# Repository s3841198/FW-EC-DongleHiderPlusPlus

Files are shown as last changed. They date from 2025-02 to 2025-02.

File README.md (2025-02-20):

# DongleHider++ Framework Laptop Expansion Card

This is a fork of LeoDJ's dongle hider plus, it is a slight refinement of the design fitting it into a pcb that is compatible with a stock Framework USB C expansion card.

Simply (permanently) mount the dongle inside the card and still have an USB A port available!  

There even is room and solder pads for an additional dongle. Your imagination (and physics) are the only limits!

See LeoDJ's [thread on Mastodon about the build process etc](https://chaos.social/@LeoDJ/112040053271880119).

<p float="left" style="display: flex; flex-wrap: wrap; align-items: center;">
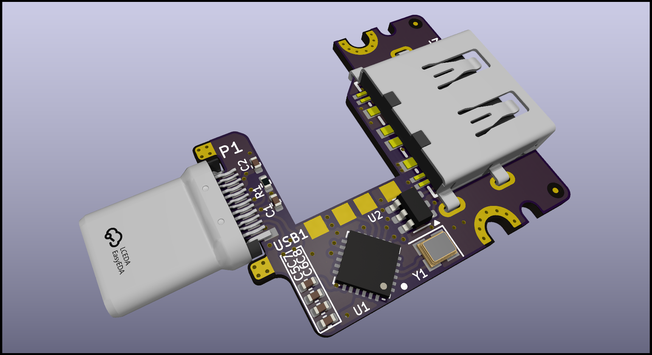
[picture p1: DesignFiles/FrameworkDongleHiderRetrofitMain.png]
  &nbsp;
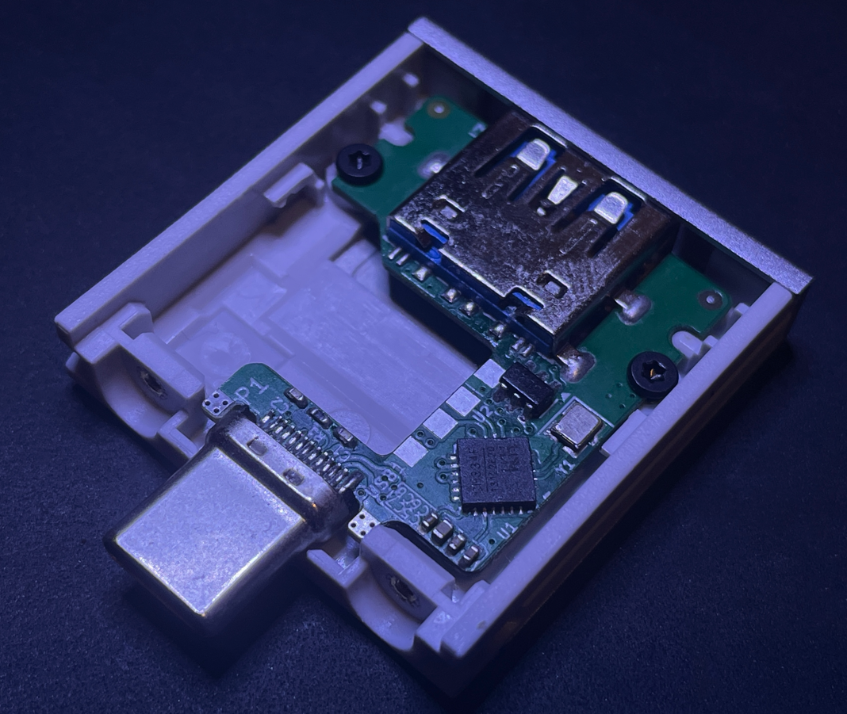
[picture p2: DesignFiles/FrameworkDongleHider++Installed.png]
  
</p>

## Compatibility Notes

The expansion card was only tested on **Windows** and **AMD** Framework **13 and 16** laptops as of right now. There the following behaviour has been observed:
- With only a dongle active, the CH334 hub IC draws around 20mA. (In addition to the ~25mA of the Unifying dongle)
  - When nothing is connected to the hub, it goes to sleep and draws <1mA. (But this is seldomly the case with a dongle permanently attached to it :P )
- Despite earlier fears, the USB 3 "route-around-2.0-hub" topology doesn't seem to cause problems in the wild, except:
- When connected to a **USB4 capable expansion card slot** and an external **USB 3 device** is plugged in, the **internal dongle stops working**, but is still displayed as connected in Windows.
  - As soon as the USB 3 device gets unplugged, the internal dongle immediately begins to work again (probably without a re-enumeration).
  - USB 2 devices seem to work without a problem for the most part, although one of the tested USB thumb drives took a few re-plugs until it enumerated.
  - This behaviour is not seen on the other non-USB4-capable expansion card slots, there USB 3 devices work great alongside the internal dongle

It's currently unclear what the behaviour would be under Linux or on Intel laptops. <sup>[You can help expand this]</sup>

### Dongles

Please note that there may be mechanical differences between the original DongleHiderPlus and this pcb, I would reccomend 3D printing the pcb outline and checking the fit of your dongle.

The Unifying dongles can be disassembled pretty easily:
|||
|---|---|
|  | **Gen 1:** <br>Carefully break off the plastic from the metal part using a pair of pliers. <br>(Can be glued back together, if needed)|
|  | **Gen 2:** <br>Slide flat screwdriver (or similar) between the metal and the orange plastic of the front of the USB a plug and carefully pry open the metal shell until it slides off. <br>[Youtube video](https://www.youtube.com/watch?v=NB5uVCrXxT8) |

## PCB
- [View the latest schematic and board view]([https://kicanvas.org/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](https://kicanvas.org/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)) thanks to KiCanvas.
- I've ordered the PCB and assembled it myself, but it should be able to be mostly assembled by PCBA services (like JLCPCB) too. The Gerber/BOM/CPL files are provided in the [PCB/jlcpcb/production_files/](FW-EC-DongleHiderPlusPlus/tree/main/jlcpcb/production_files) folder.

## Mechanical Design

- The pcb is designed to be a drop in replacement for a stock Framework USB C expansion card, it uses the original screws and doesn't require any modifications to be made to the stock housing.

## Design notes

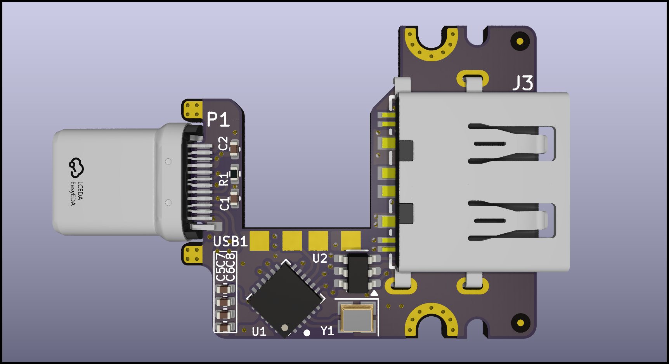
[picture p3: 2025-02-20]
DesignFiles/FrameworkDongleHiderRetrofitTOP.png

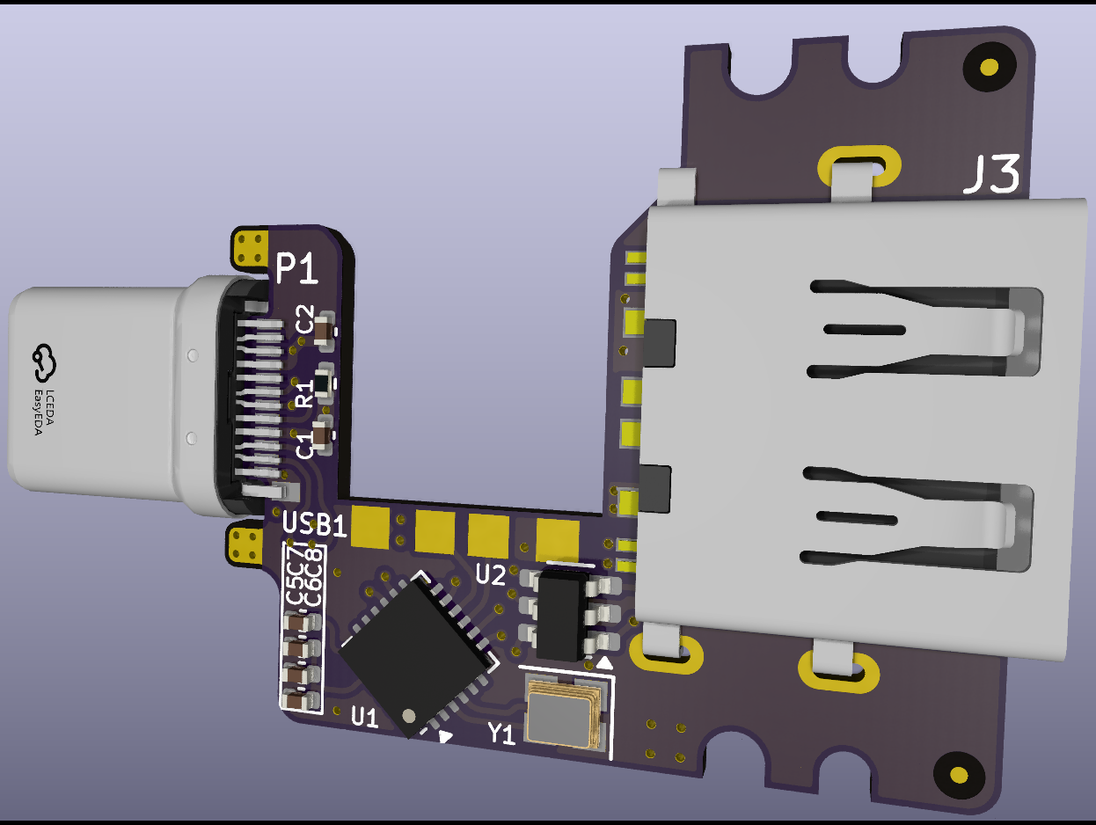
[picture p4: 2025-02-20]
FrameworkDongleHiderRetrofit.png

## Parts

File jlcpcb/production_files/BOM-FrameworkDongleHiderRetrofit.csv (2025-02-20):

Comment | Designator | Footprint | LCSC | Quantity
10n | C1,C2 | C_0402_1005Metric | C15195 | 2
10u | C6 | C_0402_1005Metric | C15525 | 1
5k1 | R1 | R_0402_1005Metric | C25905 | 1
USBLC6-2SC6 | U2 | SOT-23-6 | C2827654 | 1
12MHz | Y1 | Crystal_SMD_2520-4Pin_2.5x2.0mm | C284156 | 1
100n | C7 | C_0402_1005Metric | C307331 | 1
CH334F | U1 | QFN-24-1EP_4x4mm_P0.5mm_EP2.7x2.7mm | C5187527 | 1
1u | C5,C8 | C_0402_1005Metric | C52923 | 2
USB_C_Plug | P1 | USB_C_Plug_Molex_105444 | C561769 | 1
USB3_A | J3 | USB-A-SMD_HC-USB3.0-C345-P | C7501863 | 1

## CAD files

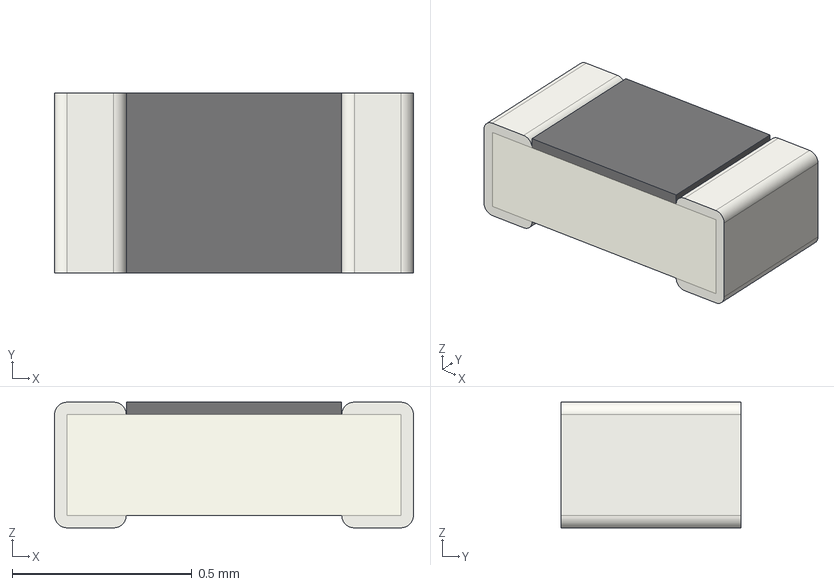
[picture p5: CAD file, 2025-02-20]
3dshapes/R_0402_1005Metric.step
1.00 x 0.5 x 0.35 mm

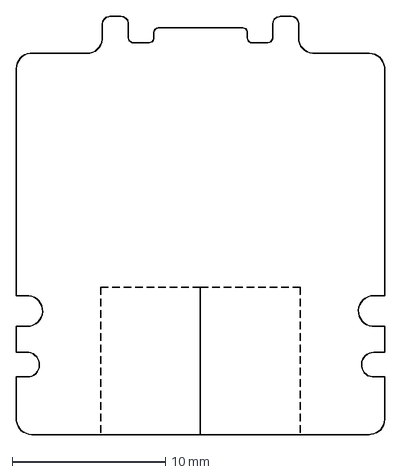
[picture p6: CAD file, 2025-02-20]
DesignFiles/FrameworkExpansionModulePCBOutline.dxf
24.0 x 27.3 mm

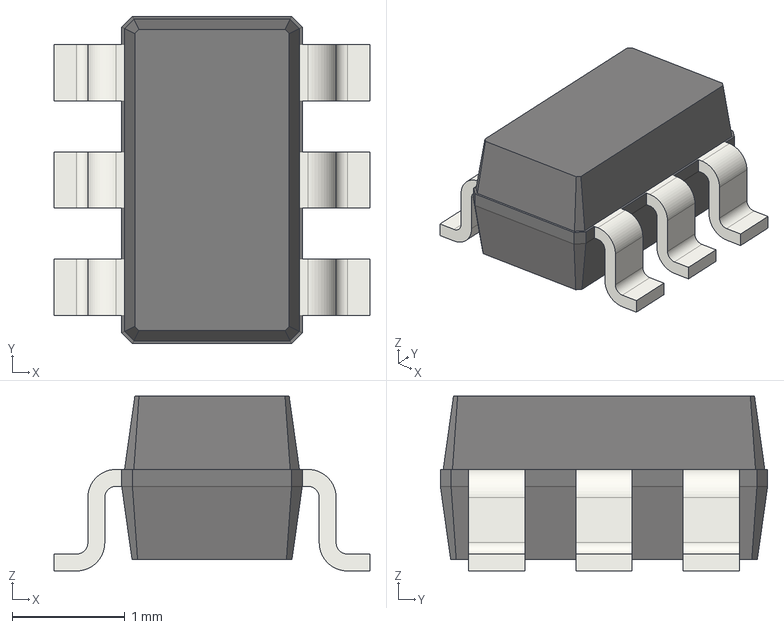
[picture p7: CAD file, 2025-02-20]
3dshapes/SOT-23-6.step
2.80 x 2.90 x 1.55 mm

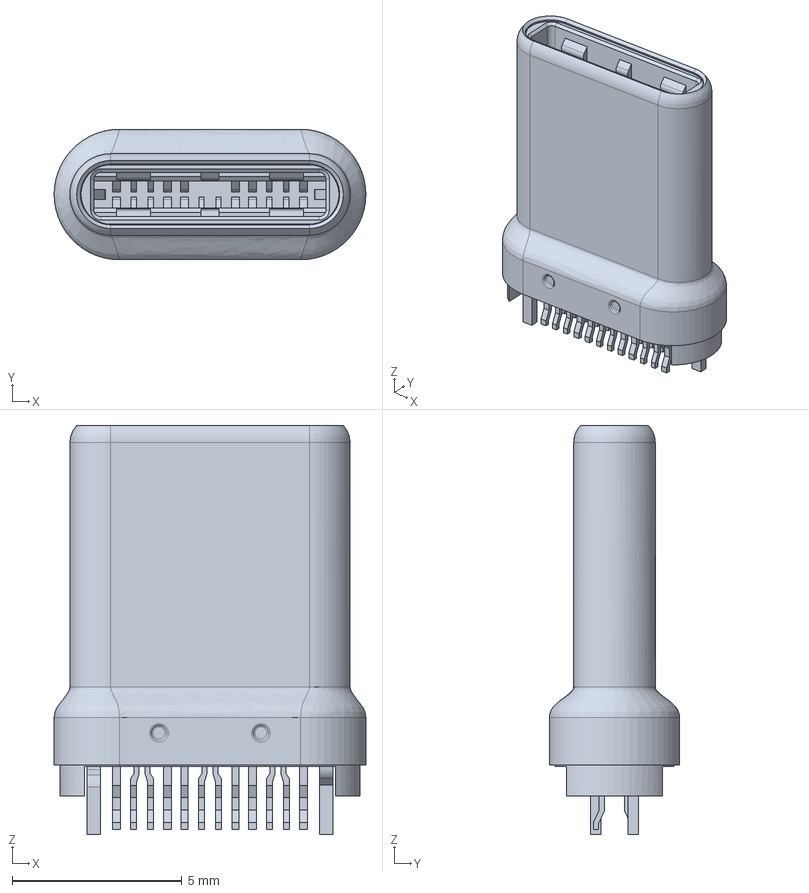
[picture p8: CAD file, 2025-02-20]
3dshapes/Molex_1054440011.stp
9.18 x 3.84 x 12.0 mm

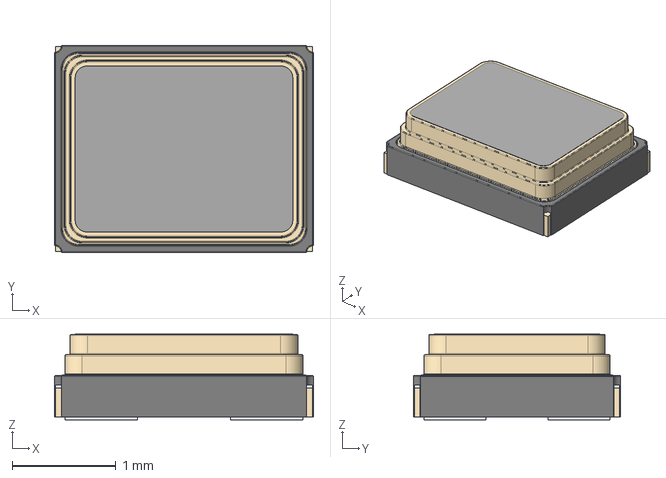
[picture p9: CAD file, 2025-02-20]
3dshapes/Crystal_SMD_2520-4Pin_2.5x2.0mm.step
2.50 x 2.00 x 0.83 mm

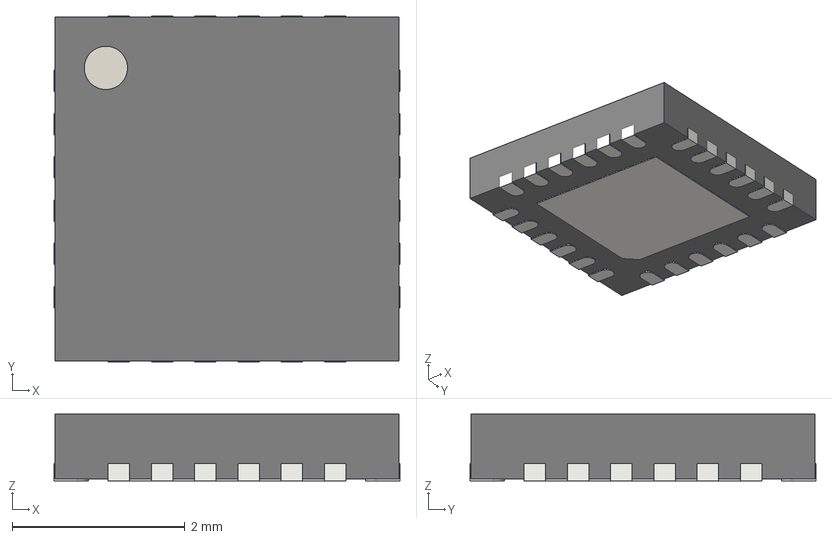
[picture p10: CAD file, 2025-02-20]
3dshapes/QFN-24-1EP_4x4mm_P0.5mm_EP2.6x2.6mm.step
4.00 x 4.00 x 0.77 mm

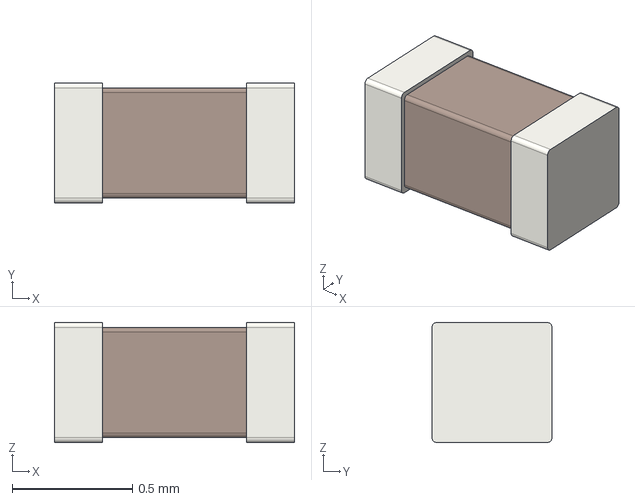
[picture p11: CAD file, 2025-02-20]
3dshapes/C_0402_1005Metric.step
1.00 x 0.5 x 0.5 mm

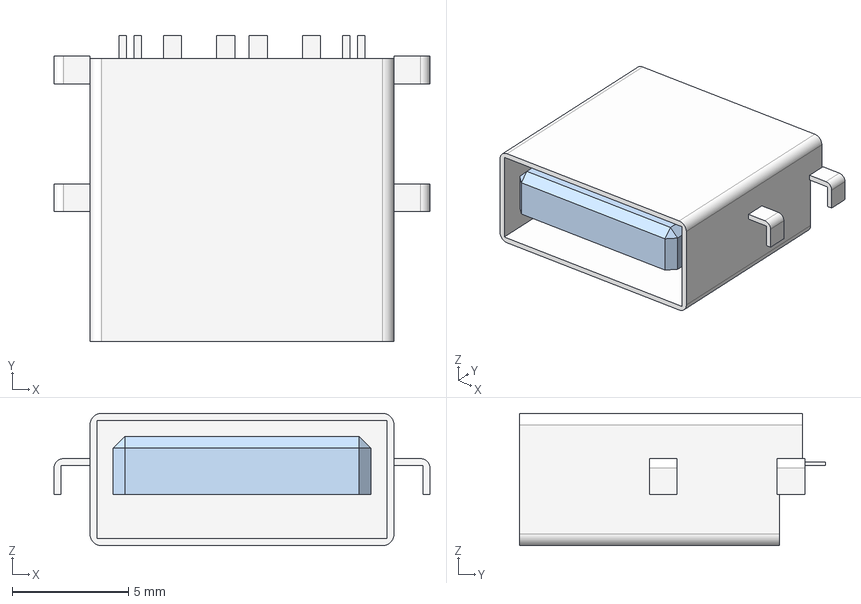
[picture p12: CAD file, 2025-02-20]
3dshapes/_HC-USB3.0-C345-P.step
16.2 x 13.2 x 5.70 mm

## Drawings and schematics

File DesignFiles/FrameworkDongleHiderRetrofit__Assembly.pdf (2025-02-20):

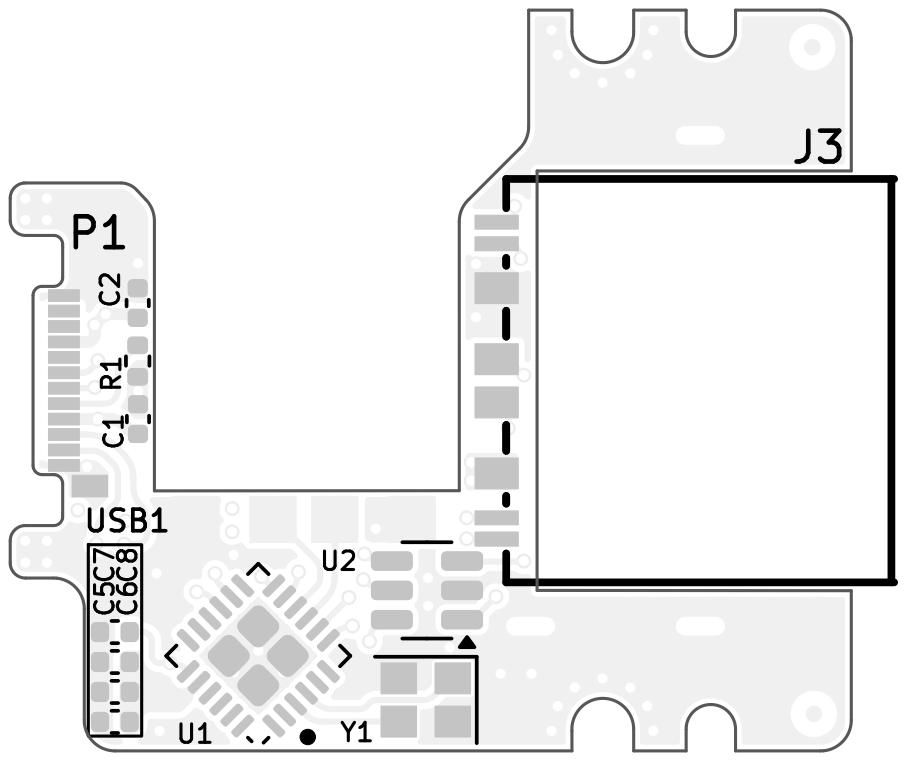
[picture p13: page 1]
D Date: KiCad; E.D.A. 8.0.8 Size: A4; Rev:; Id: 1/1 Title: File: FrameworkDongleHiderRetrofit.kicad_pcb Sheet: Black; And; White; TOP; Board2Pdf:; Black; TOP -; Page; Y1 USB1 C⁷

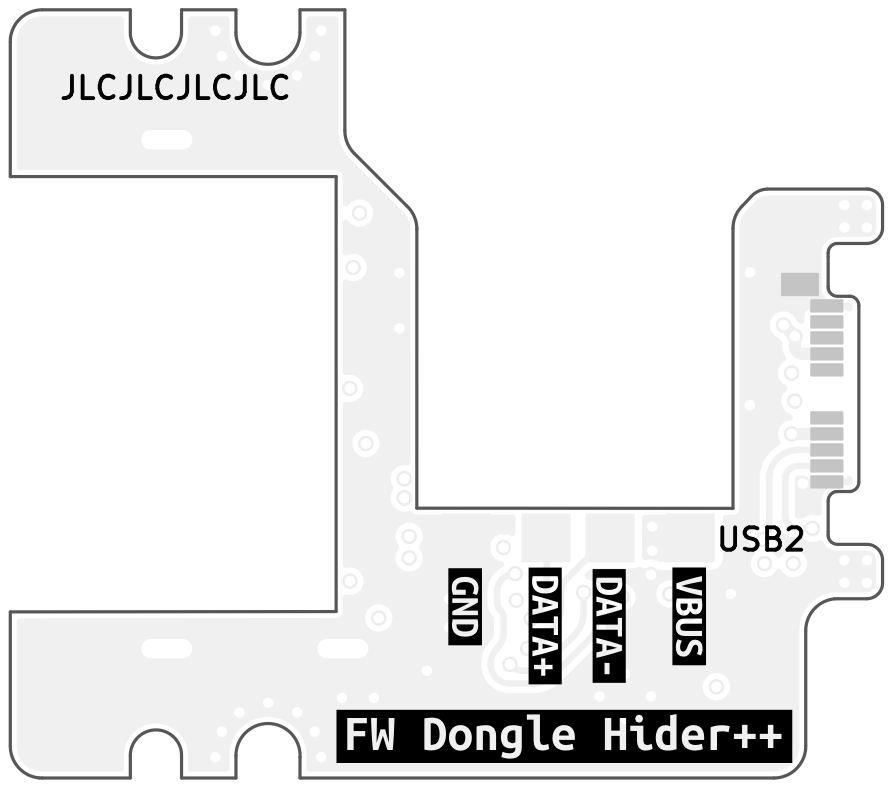
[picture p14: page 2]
D Date: KiCad; E.D.A. 8.0.8 Size: A4; Rev:; Id: 1/1 Title: File: FrameworkDongleHiderRetrofit.kicad_pcb Sheet: Black; And; White; BOT Board2Pdf:; Black; BOT -; Page 2/2; JLCJLCJLCJLC; USB2

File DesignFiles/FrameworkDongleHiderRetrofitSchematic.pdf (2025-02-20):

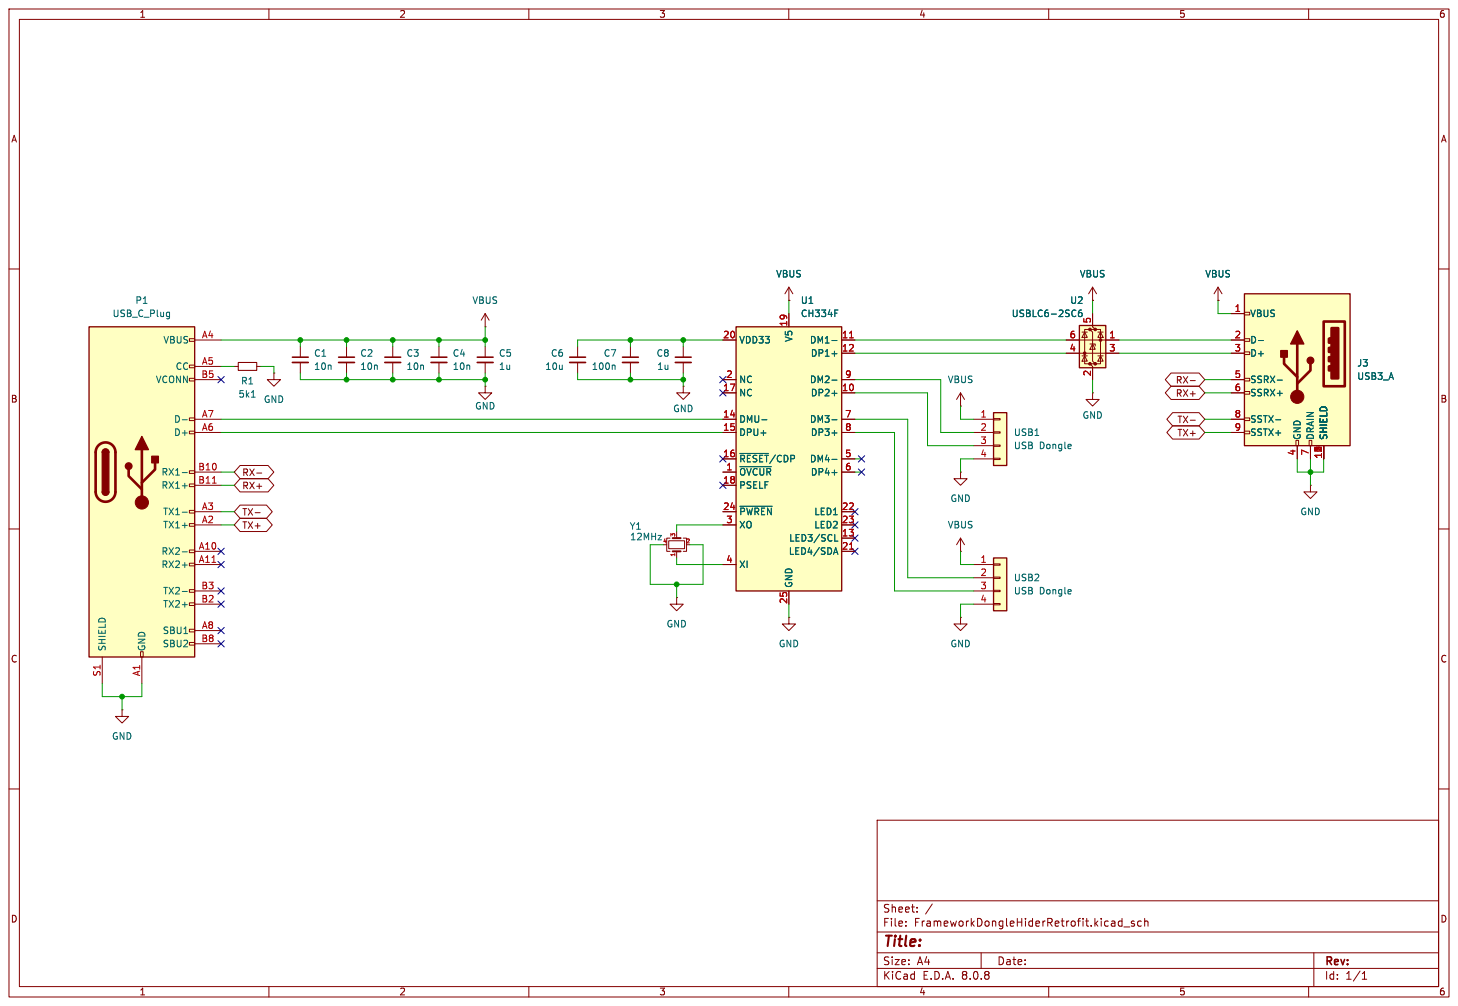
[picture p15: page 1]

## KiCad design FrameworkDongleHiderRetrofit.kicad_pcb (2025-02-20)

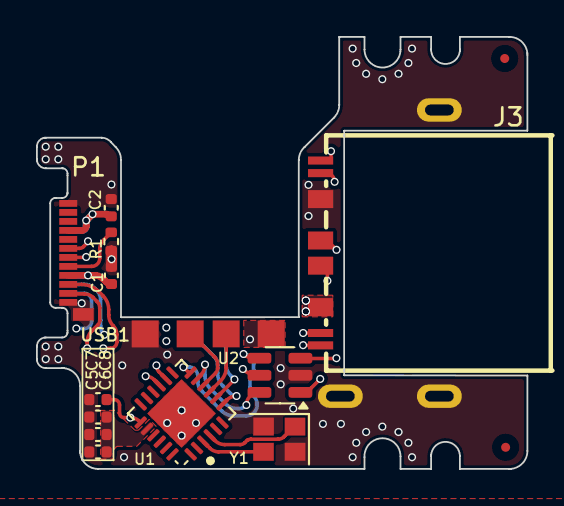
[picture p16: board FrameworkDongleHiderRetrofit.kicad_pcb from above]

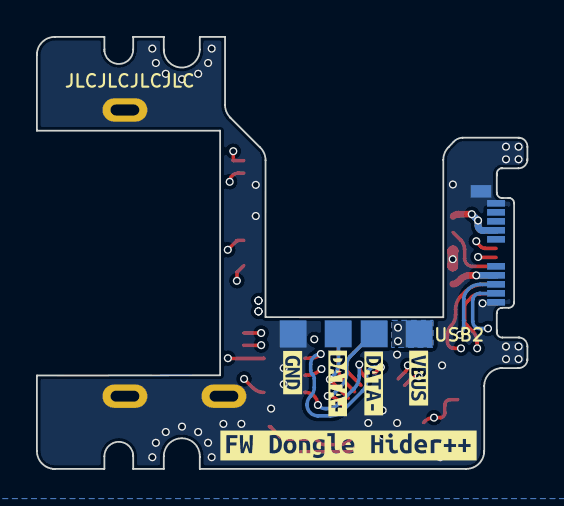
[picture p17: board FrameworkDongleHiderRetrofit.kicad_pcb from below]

Board: 4 copper layers, 27.3 x 24.0 mm, 19 parts (6 on the bottom side), 20 nets.

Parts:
C1, C2: 10n; C_0402_1005Metric
C5, C8: 1u; C_0402_1005Metric
C6: 10u; C_0402_1005Metric
C7: 100n; C_0402_1005Metric
J3: USB3_A; USB-A-SMD_HC-USB3.0-C345-P
P1: USB_C_Plug; USB_C_Plug_Molex_105444
R1: 5k1; R_0402_1005Metric
U1: CH334F; QFN-24-1EP_4x4mm_P0.5mm_EP2.7x2.7mm
U2: USBLC6-2SC6; SOT-23-6
USB1, USB2: USB Dongle; USB_SolderPads
Y1: 12MHz; Crystal_SMD_2520-4Pin_2.5x2.0mm
kibuzzard-67B71C1E: G***; kibuzzard-67B71C1E
kibuzzard-67B71C3E: G***; kibuzzard-67B71C3E
kibuzzard-67B71C39: G***; kibuzzard-67B71C39
kibuzzard-67B71C43: G***; kibuzzard-67B71C43
kibuzzard-67B71FEC: G***; kibuzzard-67B71FEC

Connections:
GND: C1.2, C2.2, C5.2, C6.2, C7.2, C8.2, J3.4 (GND), J3.10 (SHIELD), J3.11 (SHIELD), J3.12 (SHIELD), P1.A1 (GND), P1.A12 (GND), P1.B1 (GND), P1.B12 (GND), P1.S1 (SHIELD), R1.2, U1.25 (GND), U2.2 (GND), USB1.4, USB2.4, Y1.2, Y1.4
unnamed: J3.3 (D+), U2.3 (I/O2)
unnamed: J3.2 (D-), U2.1 (I/O1)
unnamed: P1.A5 (CC), R1.1
unnamed: P1.A6 (D+), U1.15 (DPU+)
unnamed: P1.A7 (D-), U1.14 (DMU-)
unnamed: U1.11 (DM1-), U2.6 (I/O1)
unnamed: U1.9 (DM2-), USB1.2
unnamed: U1.7 (DM3-), USB2.2
unnamed: U1.12 (DP1+), U2.4 (I/O2)
unnamed: U1.10 (DP2+), USB1.3
unnamed: U1.8 (DP3+), USB2.3
unnamed: C6.1, C7.1, C8.1, U1.20 (VDD33)
unnamed: U1.4 (XI), Y1.1
unnamed: U1.3 (XO), Y1.3
RX+: J3.6 (SSRX+), P1.B11 (RX1+)
RX-: J3.5 (SSRX-), P1.B10 (RX1-)
TX+: J3.9 (SSTX+), P1.A2 (TX1+)
TX-: J3.8 (SSTX-), P1.A3 (TX1-)
VBUS: C1.1, C2.1, C5.1, J3.1 (VBUS), P1.A4 (VBUS), P1.A9 (VBUS), P1.B4 (VBUS), P1.B9 (VBUS), U1.19 (V5), U2.5 (VBUS), USB1.1, USB2.1

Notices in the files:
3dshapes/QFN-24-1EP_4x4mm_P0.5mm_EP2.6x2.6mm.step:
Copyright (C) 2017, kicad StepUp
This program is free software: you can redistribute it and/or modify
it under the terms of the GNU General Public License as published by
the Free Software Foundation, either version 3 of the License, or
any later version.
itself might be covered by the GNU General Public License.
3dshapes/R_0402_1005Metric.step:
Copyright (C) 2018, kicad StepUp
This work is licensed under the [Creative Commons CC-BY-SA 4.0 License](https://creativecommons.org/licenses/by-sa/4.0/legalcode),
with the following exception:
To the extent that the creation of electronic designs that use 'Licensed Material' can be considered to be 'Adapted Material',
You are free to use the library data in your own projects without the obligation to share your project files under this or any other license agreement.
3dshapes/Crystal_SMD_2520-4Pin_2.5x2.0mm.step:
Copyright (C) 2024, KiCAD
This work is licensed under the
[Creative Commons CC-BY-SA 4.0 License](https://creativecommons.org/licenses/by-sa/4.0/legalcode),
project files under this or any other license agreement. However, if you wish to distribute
